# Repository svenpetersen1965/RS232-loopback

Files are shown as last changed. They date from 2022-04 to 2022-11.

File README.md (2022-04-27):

# RS232-loopback
This is a loopback module for the serial interface (RS232 and TTL).

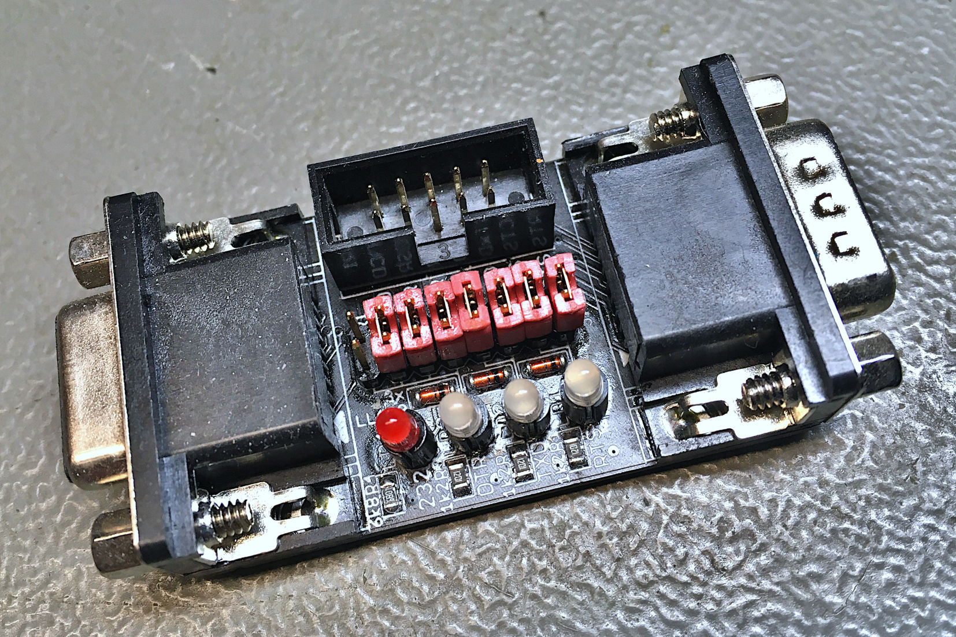
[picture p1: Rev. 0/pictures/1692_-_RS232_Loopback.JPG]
RS-232 loopback


It is useful for testing a serial interface. The sent data is echoed back, the RTS is fed back to CTS and DTR is looped back to DSR, DCD and RI. The feedbacks can be jumpered, the status is indicated on LEDs and it connects to DTE and DCE (9 pin D-Sub connectors). Also, there is a box connector for connecting a ribbon cable.

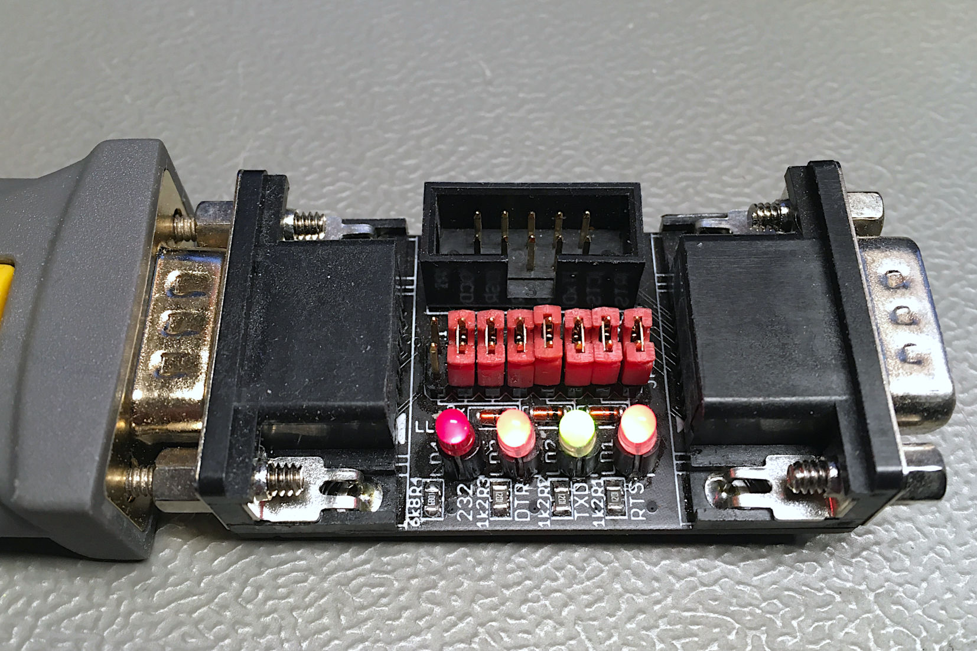
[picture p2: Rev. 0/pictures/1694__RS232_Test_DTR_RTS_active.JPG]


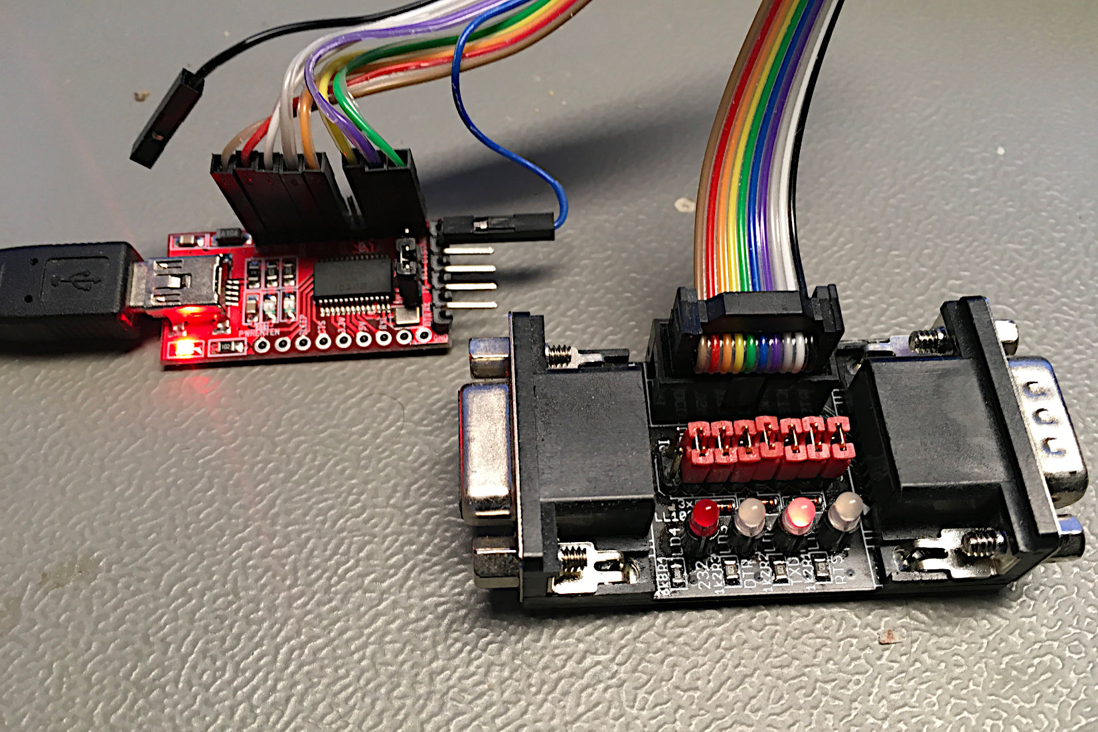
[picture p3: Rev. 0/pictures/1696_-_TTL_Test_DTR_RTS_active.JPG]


Please refer to the documentation in the pdf subdirectory.

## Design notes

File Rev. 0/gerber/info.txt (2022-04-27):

      
       Board: RS-232 Loopback
       Rev.:  0
  
       Files:
       ======
  
       All Gerber files are generated in extended gerber format (RS274X)
       *.TOP        : Film top copper
       *.BOT        :  -"- bottom copper
       *.STC        :  -"- top soldermask 
       *.STS        :  -"- bottom soldermask
       *.PLC        :  -"- silk screen top
       *.PLS        :  -"- silk screen bottom
       *.CRC        :  -"- cream top
       *.DK         : Drills plated Through (Excellon)
       *.NDK        : Drills not plated Through (Excellon)
       *.OUT        : Board outline

       Board Size:
       ===========
       Length     :   54.5 mm
       Width      :   30.5 mm
       Thickness  :   1.6 mm
       Material   :   FR 4
       Copper     :   35 um
       Surface    :   HASL
       
       Remarks: 
       ========

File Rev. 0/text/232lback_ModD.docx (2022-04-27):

RS-232 Loopback Rev.0

Module description

# Introduction

The RS-232 loopback is a tool for testing or sniffing an RS-232/TTL serial interface. It has a female (DTE/computer side) D-Sub (9 pins) connector, a male (DCE/modem side) D-Sub (9 pin) and a 2x5 box connector/pin header, which is configured for connecting the RS232 via a ribbon cable.

There are three feedbacks, that can be jumpered. The status of each feedback is indicated with a bi-color LED.

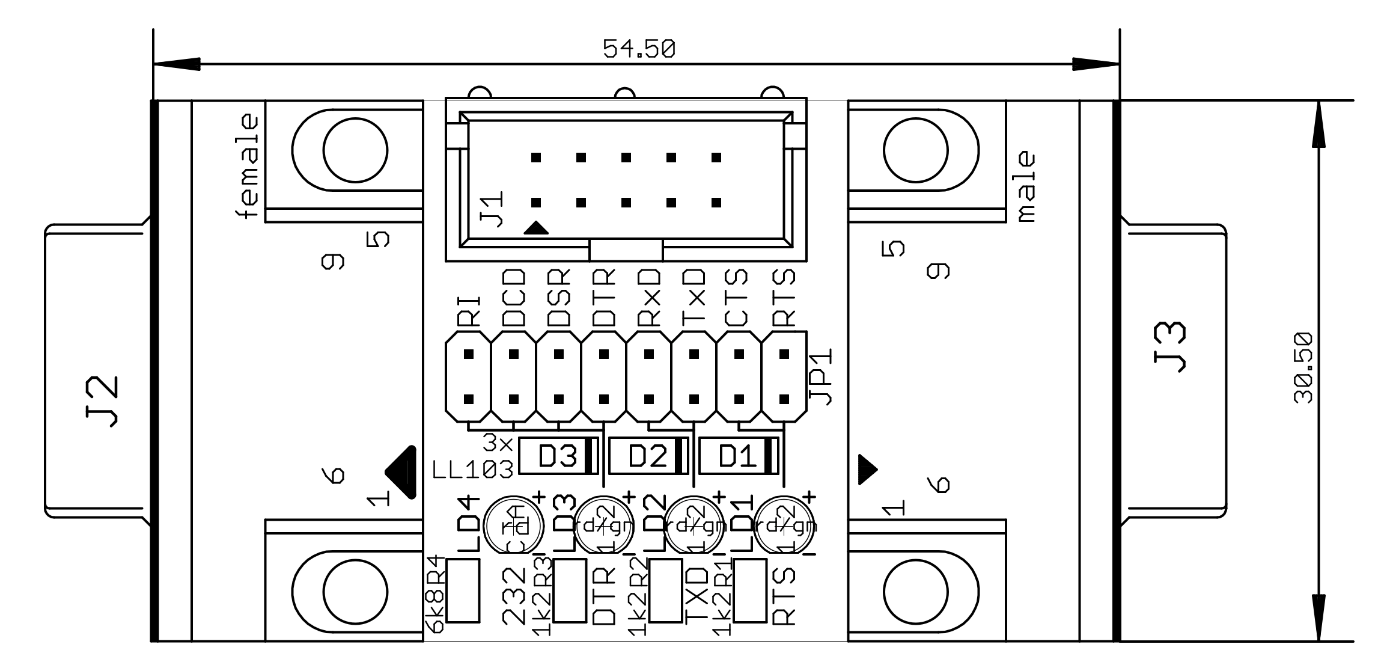
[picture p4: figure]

Figure 1: Dimensions of the RS-232 Loopback

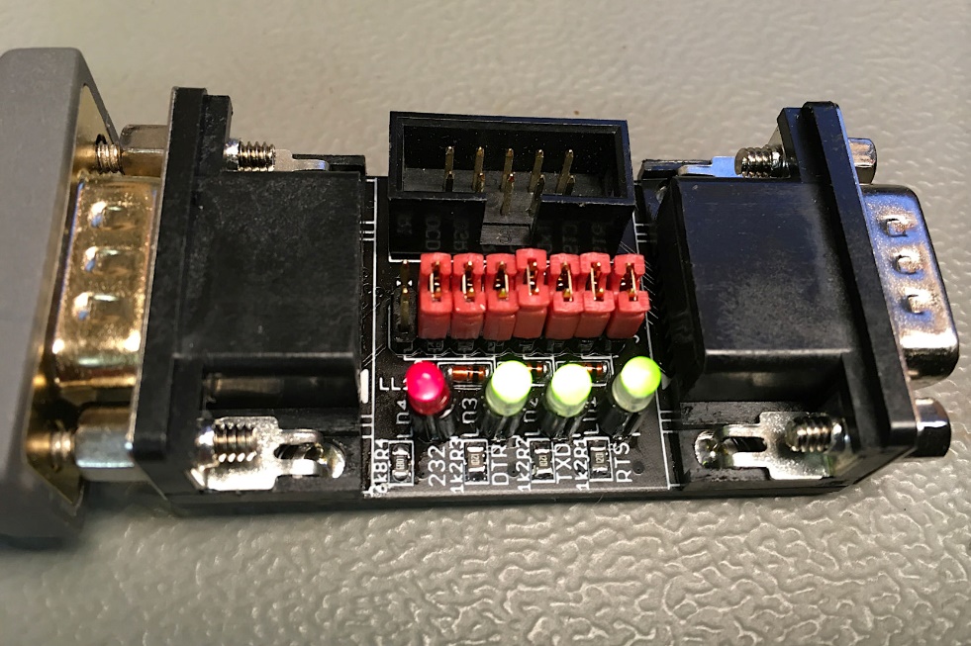
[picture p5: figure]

Figure 2: Connected RS-232 loopback

# Feedbacks /Jumper/Indicators

## Jumper J1

Feedback | Signals | Jumper JP1 | LED
RTS | RTS CTS | 1-2 3-4 | LD1
TXD | TxD RxD | 5-6 7-8 | LD2
DTR | DTR DSR DCD RI | 9-10 11-12 13-14 15-16 | LD3

## LEDs

### RS-232

RxD, TxD: The voltage level for a logic “0” (aka “space”) is +3V to +15V, for logic “1” (aka “mark”) it is -3V to -15V. voltages between -3V to +3V are an “illegal state”. For the handshake signals (RTS, CTS, DTR, DSR, DCD and RI) active is a positive +3V to +15V, while not active is negative -3V to -15V).

The RTS and DTR LEDs are red while active and green while not active. When idle, the TxD LED LD2 is green (indicating a negative voltage level) and blinking while data is being transferred.

### TTL

The RTS and DTR LEDs are off while active (LOW) and red while not active (HIGH). These signals are active low in TTL level). While idle, the TxD LED (LD2) is on.

### Level Indicator

There is a 4th LED (LD4) indicating the level: RS-232 (on), TTL (off).

# Connectors

## J1 (Box connector to DTE/Computer)

This is a 2x5 pin box connector. It is configured to fit a ribbon cable to a 2.54mm pitch pin header on a motherboard of a computer or to connect a D-Sub connector

Signal | Pin | Pin | Signal
DCD | 1 | 2 | DSR
RxD | 3 | 4 | RTS
TxD | 5 | 6 | CTS
DTR | 7 | 8 | RI
GND | 9 | 10 | -

## J2 (to DTE/Computer)

This is a female 9 pin D-Sub connector. It has the standard pinout of a modem side and fits directly or via a modem cable into the serial port of a computer.

Signal | Pin | Pin | Signal
DCD | 1 | 6 | DSR
RxD | 2 | 7 | RTS
TxD | 3 | 8 | CTS
DTR | 4 | 9 | RI
GND | 5

## J3 (to DCE/modem)

This is a male 9 pin D-Sub connector. It has the standard pinout of the serial interface of a computer/DTE and fits directly or via a modem cable into the serial port of a modem/DCE.

Signal | Pin | Pin | Signal
DSR | 6 | 1 | DCD
RTS | 7 | 2 | RxD
CTS | 8 | 3 | TxD
RI | 9 | 4 | DTR
| | 5 | GND

# Revision History

## Rev. 0

- Prototype: fully functional

232lback_ModD.docx 27.04.2022 16:35 Drafted by Sven Petersen Page 2 of 2 Doc.-No.: 183-6-01-00

232lback_ModD.docx 27.04.2022 16:35 Drafted by Sven Petersen Page 1 of 1 Doc.-No.: 000-6-00-00

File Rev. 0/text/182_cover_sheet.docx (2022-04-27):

Project Documentation

RS-232 Loopback

Project number: 183

Revision: 0

Date: 27.04.2022

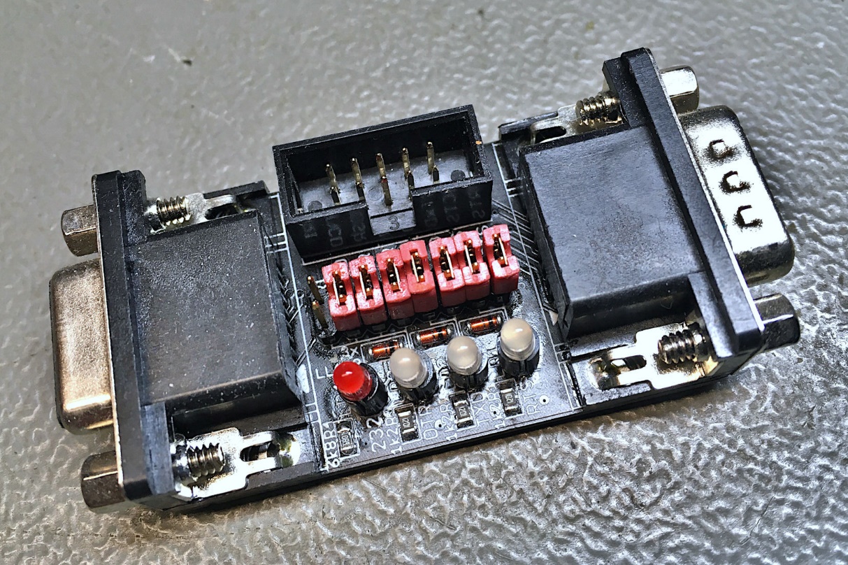
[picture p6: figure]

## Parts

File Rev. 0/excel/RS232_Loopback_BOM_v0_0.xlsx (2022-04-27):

RS-232 Loopback Rev. 0
Bill of Material Rev. 0.0
Pos. | Qty | Value | Footprint | Ref.-No. | Comment
1 | 1 | 183-2-01-00 | 2 Layer | PCB Rev. 0 | 2 layer, Cu 35µ, HASL, 54.5mm x 30.5mm, 1.6mm FR4
2 | 1 | box header, 2x5, 2.54mm | 2X05WV | J1 | e.g. Reichelt WSL 10G
3 | 1 | LED, 3mm green | 3MM | LD4 | standard LED
4 | 3 | 1k2 | 805 | R1, R2, R3 | SMD metal film resistor, 5% or better
5 | 1 | 6k8 | 805 | R4 | SMD metal film resistor, 5% or better
6 | 1 | COMBI-8X2P | COMBI-8X2 | JP1 | solder bridges or 2x8 pin header
7 | 8 | Jumper, 2.54mm | jumper | (JP1) | standard jumper (rated 1A or more). E.G. Reichelt: JUMPER 2,54 SW, tme.eu: 63429-202LF
8 | 1 | D09F90CL | D09F90CL | J2 | DSUB, 9p, female, 90°. E.g. Reichelt D-SUB BU 09EU
9 | 1 | D09M90CL | D09M90CL | J3 | DSUB, 9p, male, 90°. E.g. Reichelt D-SUB ST 09EU
10 | 3 | L-937EGW | LED_3MM_BICOLOR | LD1, LD2, LD3 | bi-color 3mm LED (green, red), e.g. Kingbright, e.g. Reichelt LED 3 RG
11 | 3 | LL103A | SOD-80 | D1, D2, D3 | SMD schottky diode, e.g. Vishay

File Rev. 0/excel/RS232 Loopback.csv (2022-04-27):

Qty | Value | Device | Package | Parts | Description
1 |  | 2X05WV | 2X05WV | J1
1 |  | 3MM | 3MM | LD4
3 | 1k2 | R-0805 | 0805 | R1, R2, R3
1 | 6k8 | R-0805 | 0805 | R4
1 | COMBI-8X2P | COMBI-8X2P | COMBI-8X2 | JP1
1 | D09F90CL | D09F90CL | D09F90CL | J2
1 | D09M90CL | D09M90CL | D09M90CL | J3
3 | L-937EGW | L-937EGW | LED_3MM_BICOLOR | LD1, LD2, LD3
3 | LL103A | D-SOD80 | SOD-80 | D1, D2, D3
1 | OPEN_SOURCE_HW | OPEN_SOURCE_HW | OPENHW | U$44

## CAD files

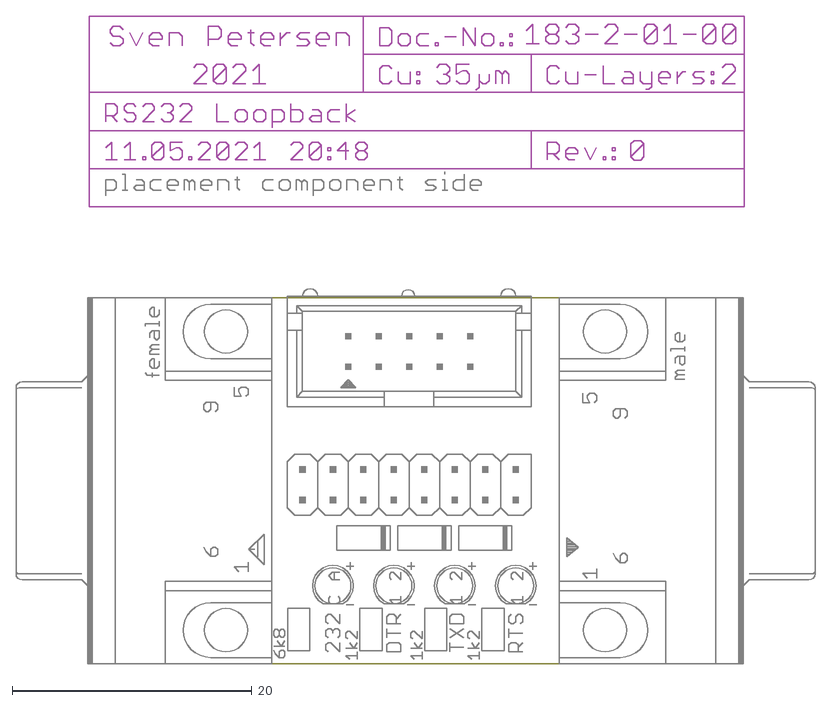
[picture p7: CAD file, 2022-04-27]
Rev. 0/dxf/RS232 Loopback.dxf
66.6 x 54.0

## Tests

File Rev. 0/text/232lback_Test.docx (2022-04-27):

RS-232 Loopback Rev.0

Testing

# Test Setup

1. RS-232 Loopback Rev. 0 (DUT, device under test)
2. USB to RS-232 converter/cable
3. USB to Serial (TTL/3.3V) converter board with FTDI FT232
4. Ribbon cable (Box connector to Dupont)
5. Terminal Software YAT (https://sourceforge.net/projects/y-a-terminal/)

The DUT was either connected via the serial cable or the FTDI board to the computer. The proper COM-port was selected in YAT.

# Test Execution

## Test via the USB to RS-232

For the test, all jumpers except the RI jumper were placed. The selected (YAT) baud rate was 9600.

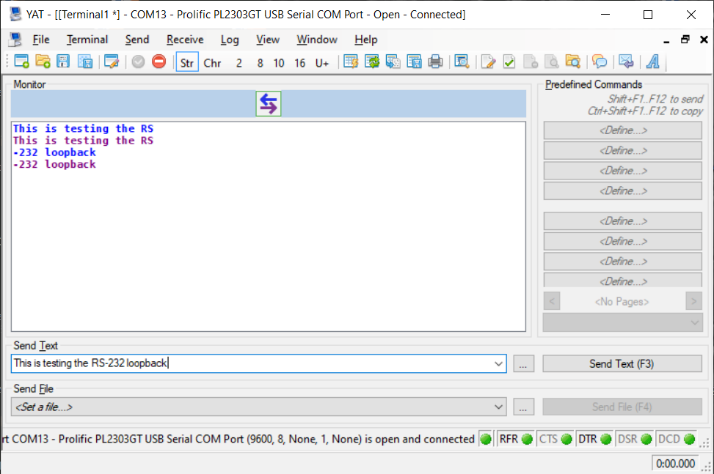
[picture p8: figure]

Figure 1: YAT - First test RTS (RFR) and DTS active

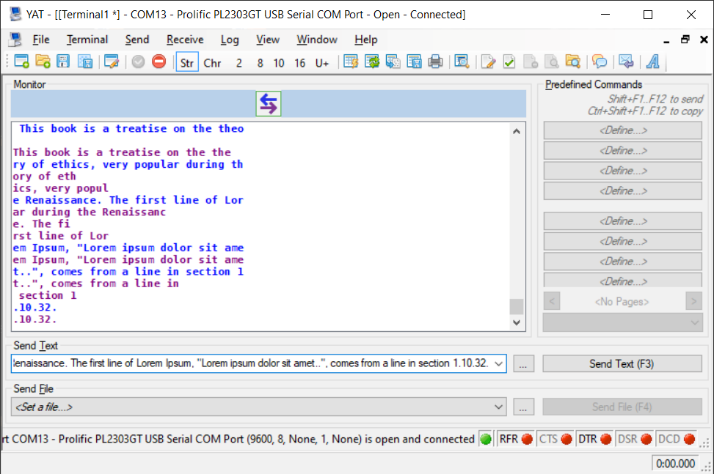
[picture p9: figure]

Figure 2: YAT - further testing RTS (RFR) and DTR inactive

While the data (text) is being transferred, the TxD LED LD2 is flickering. The sent text is being echoed by the loopback (as desired). The received (looped back) text is identical with the sent text. The line break is not, which is matter of the software.

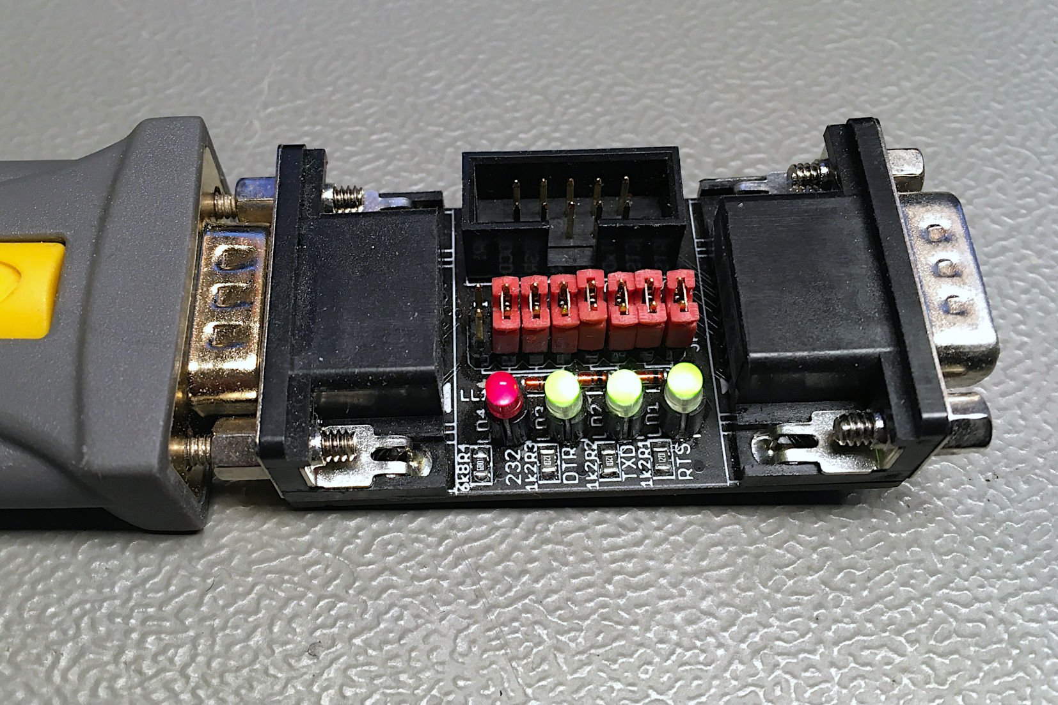
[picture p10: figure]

Figure 3: The RS-232 loopback connected to the RS-232 cable, RTS and DTR is inactive

The Level-Indicator LED lights (dim), while inactive and idling, all three bi-color LEDs (LD1-3) are green.


Figure 4: connected to RS-232, RTS and DTR active

When the status of RFR (RTS) is changed, the looped back status on CTS (indicated by YAT) changes accordingly. The same happens with DSR and DCD, if the DTR status is changed.

## Test via the USB to serial board (TTL)

The USB to serial board is connected to the box connector with the ribbon cable.


Figure 5: Test with the USB - (TTL) serial converter. Status: idle, RTS and DTR active

The level indicator LED LD4 (left, Figure 5) is off.

While data is being transferred, the TXD LED (LD2) is flickering. The RTS LED (LD1) is off while active and on while RTS is inactive. The DTR LED (LD3) indicated the DTR status correctly, too. The transmitted data is echoed back and the (this way) received text is identical with the transmitted text.

# Conclusion

The prototype is fully functional.

232lback_Test.docx 27.04.2022 16:35 Drafted by Sven Petersen Page 2 of 2 Doc.-No.: 183-6-02-00

232lback_Test.docx 27.04.2022 16:35 Drafted by Sven Petersen Page 1 of 1 Doc.-No.: 000-6-00-00

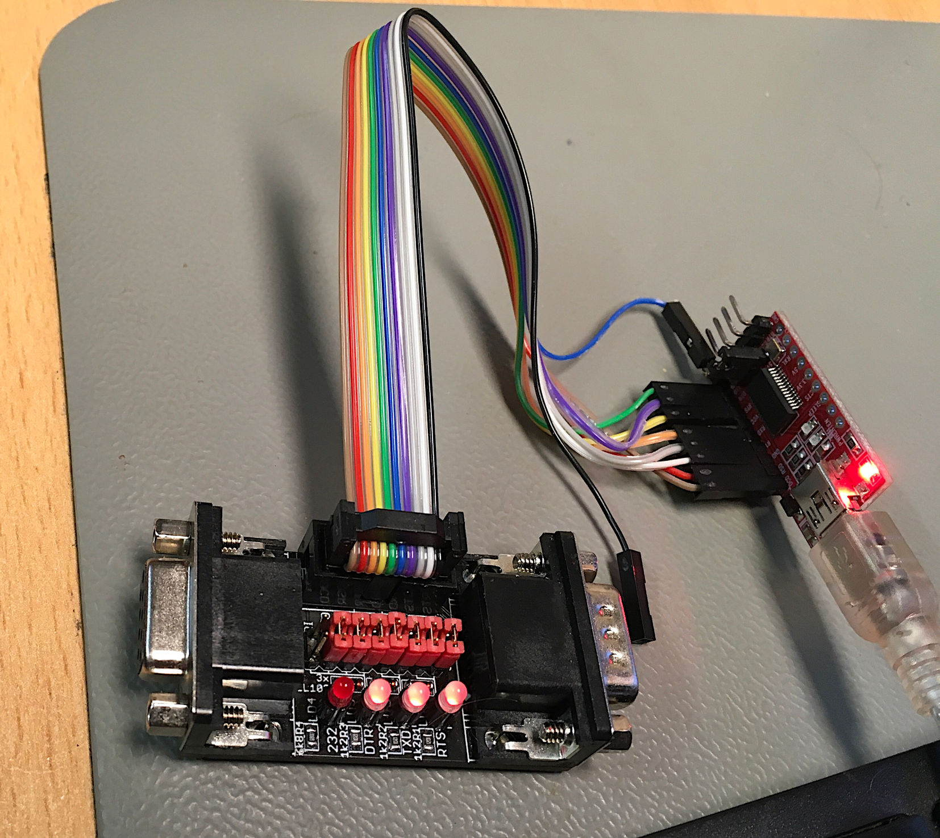
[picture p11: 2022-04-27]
Rev. 0/pictures/9595_-__TTL_Test_DTR_RTS_inactive.JPG

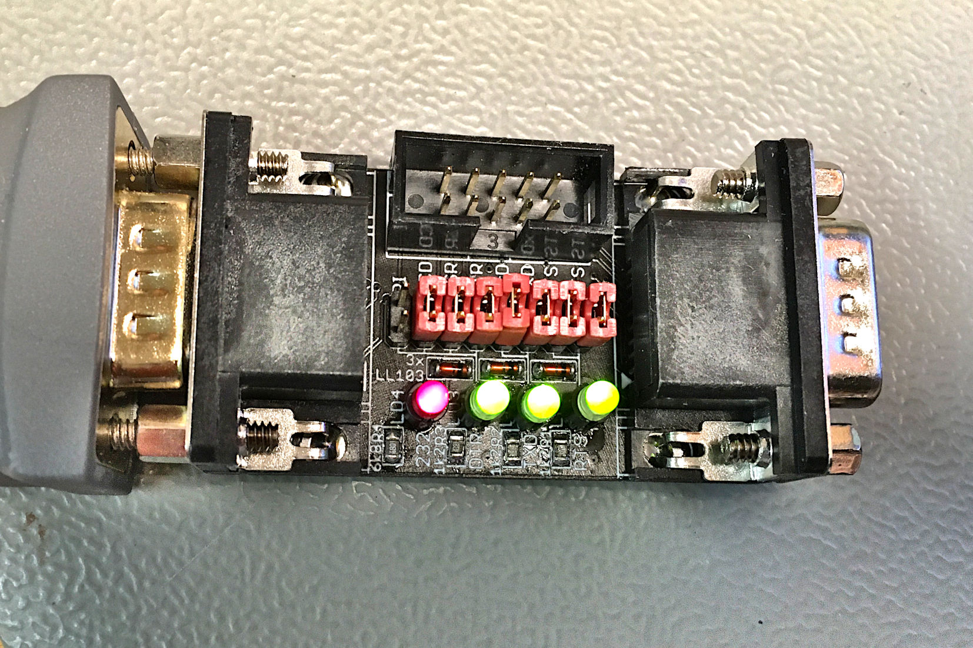
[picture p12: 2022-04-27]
Rev. 0/pictures/9485_-_Test_RS232_DTR_RTS_inactive.JPG

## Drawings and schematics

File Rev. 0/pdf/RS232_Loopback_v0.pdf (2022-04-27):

# Project Documentation

## RS-232 Loopback

## Project number: 183

## Revision: 0

## Date: 27.04.2022

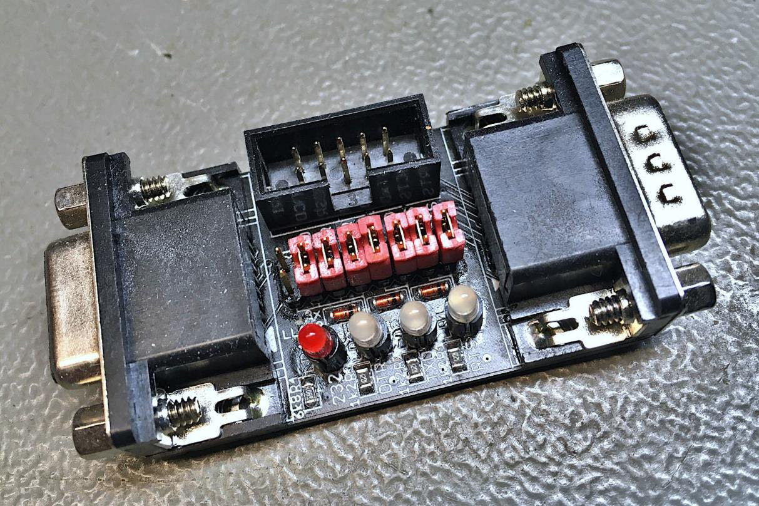
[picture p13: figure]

### RS-232 Loopback Rev.0

### Module description

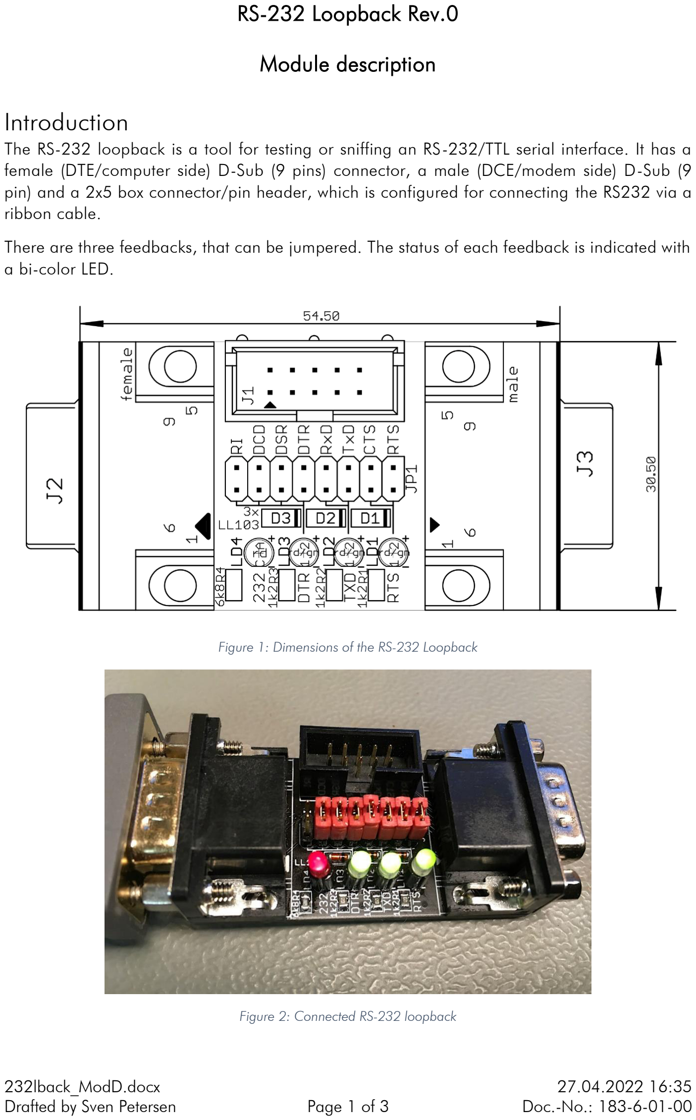
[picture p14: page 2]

232lback_ModD.docx | | 27.04.2022 16:35
Drafted by Sven Petersen | Page 1 of 3 | Doc.-No.: 183-6-01-00

## Introduction

The RS-232 loopback is a tool for testing or sniffing an RS-232/TTL serial interface. It has a female (DTE/computer side) D-Sub (9 pins) connector, a male (DCE/modem side) D-Sub (9 pin) and a 2x5 box connector/pin header, which is configured for connecting the RS232 via a ribbon cable.

There are three feedbacks, that can be jumpered. The status of each feedback is indicated with a bi-color LED.

Figure 1: Dimensions of the RS-232 Loopback

Figure 2: Connected RS-232 loopback

232lback_ModD.docx | | 27.04.2022 16:35
Drafted by Sven Petersen | Page 2 of 3 | Doc.-No.: 183-6-01-00

## Feedbacks /Jumper/Indicators

### Jumper J1

Feedback | Signals | Jumper JP1

LED

RTS | RTS CTS | 1-2 3-4 | LD1
TXD | TxD RxD | 5-6 7-8 | LD2
DTR | DTR DSR DCD RI | 9-10 11-12 13-14 15-16 | LD3

### LEDs

RS-232
RxD, TxD: The voltage level for a logic “0” (aka “space”) is +3V to +15V, for logic “1” (aka “mark”) it is -3V to -15V. voltages between -3V to +3V are an “illegal state”. For the handshake signals (RTS, CTS, DTR, DSR, DCD and RI) active is a positive +3V to +15V, while not active is negative -3V to -15V).

The RTS and DTR LEDs are red while active and green while not active. When idle, the TxD LED LD2 is green (indicating a negative voltage level) and blinking while data is being transferred.

TTL
The RTS and DTR LEDs are off while active (LOW) and red while not active (HIGH). These signals are active low in TTL level). While idle, the TxD LED (LD2) is on.

Level Indicator
There is a 4th LED (LD4) indicating the level: RS-232 (on), TTL (off).

## Connectors

### J1 (Box connector to DTE/Computer)

This is a 2x5 pin box connector. It is configured to fit a ribbon cable to a 2.54mm pitch pin header on a motherboard of a computer or to connect a D-Sub connector

Signal Pin | Pin Signal
DCD | 1 | 2 | DSR
RxD | 3 | 4 | RTS
TxD | 5 | 6 | CTS
DTR | 7 | 8 | RI
GND | 9 | 10 | -

### J2 (to DTE/Computer)

This is a female 9 pin D-Sub connector. It has the standard pinout of a modem side and fits directly or via a modem cable into the serial port of a computer.

Signal Pin | Pin Signal
DCD | 1 | 6 | DSR

232lback_ModD.docx | | 27.04.2022 16:35
Drafted by Sven Petersen | Page 3 of 3 | Doc.-No.: 183-6-01-00
RxD | 2 | 7 | RTS
TxD | 3 | 8 | CTS
DTR | 4 | 9 | RI
GND | 5

### J3 (to DCE/modem)

This is a male 9 pin D-Sub connector. It has the standard pinout of the serial interface of a computer/DTE and fits directly or via a modem cable into the serial port of a modem/DCE.

Signal Pin | Pin Signal
DSR | 6 | 1 | DCD
RTS | 7 | 2 | RxD
CTS | 8 | 3 | TxD
RI | 9 | 4 | DTR
| | 5 GND

## Revision History

### Rev. 0

- Prototype: fully functional

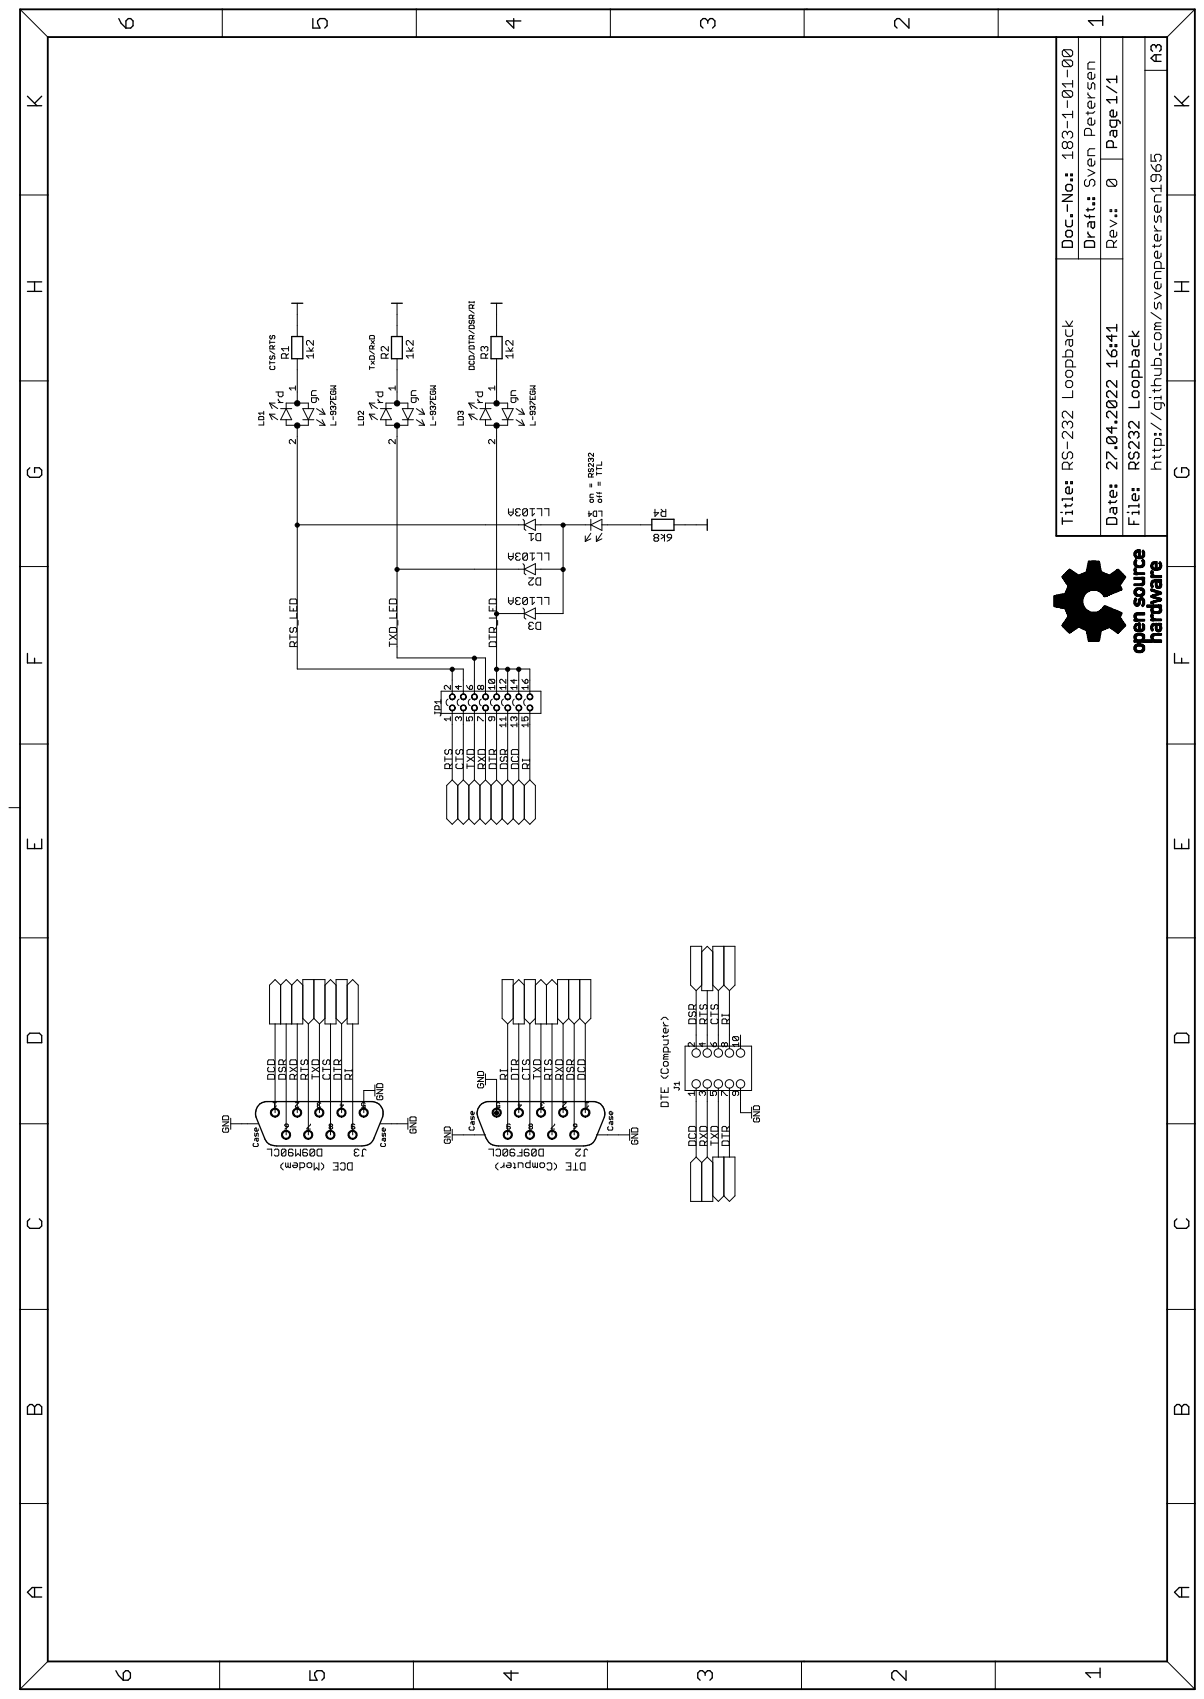
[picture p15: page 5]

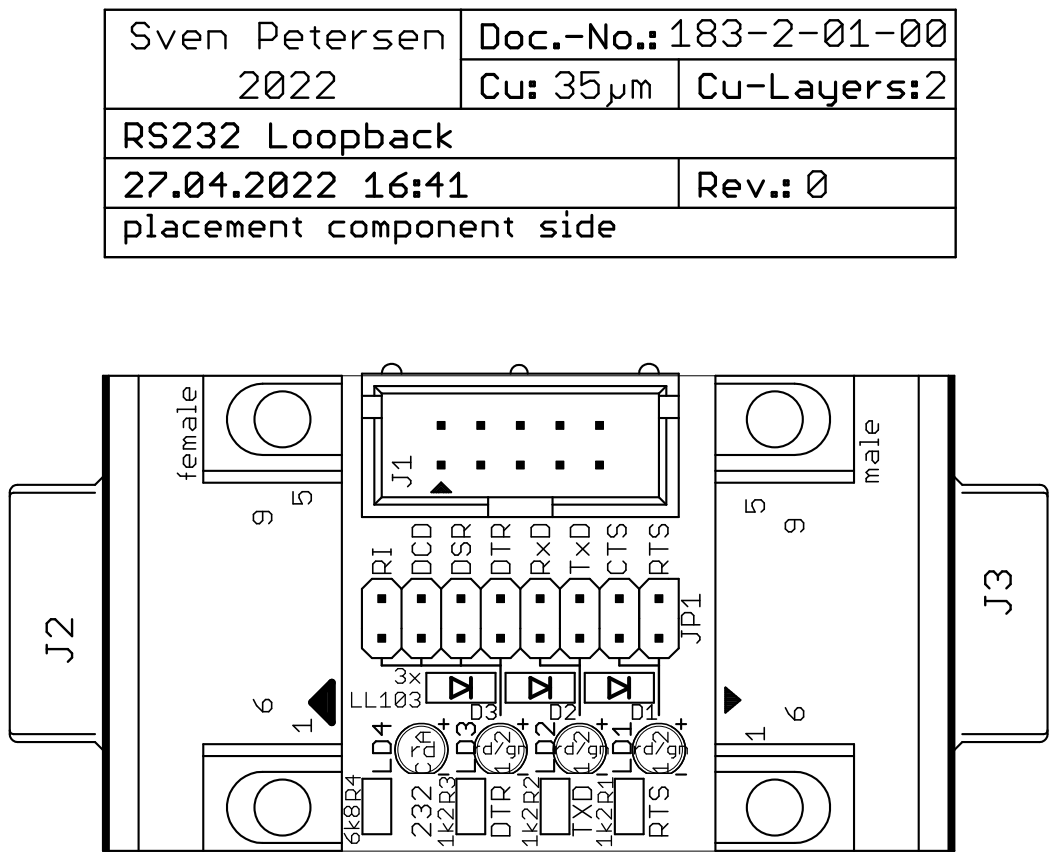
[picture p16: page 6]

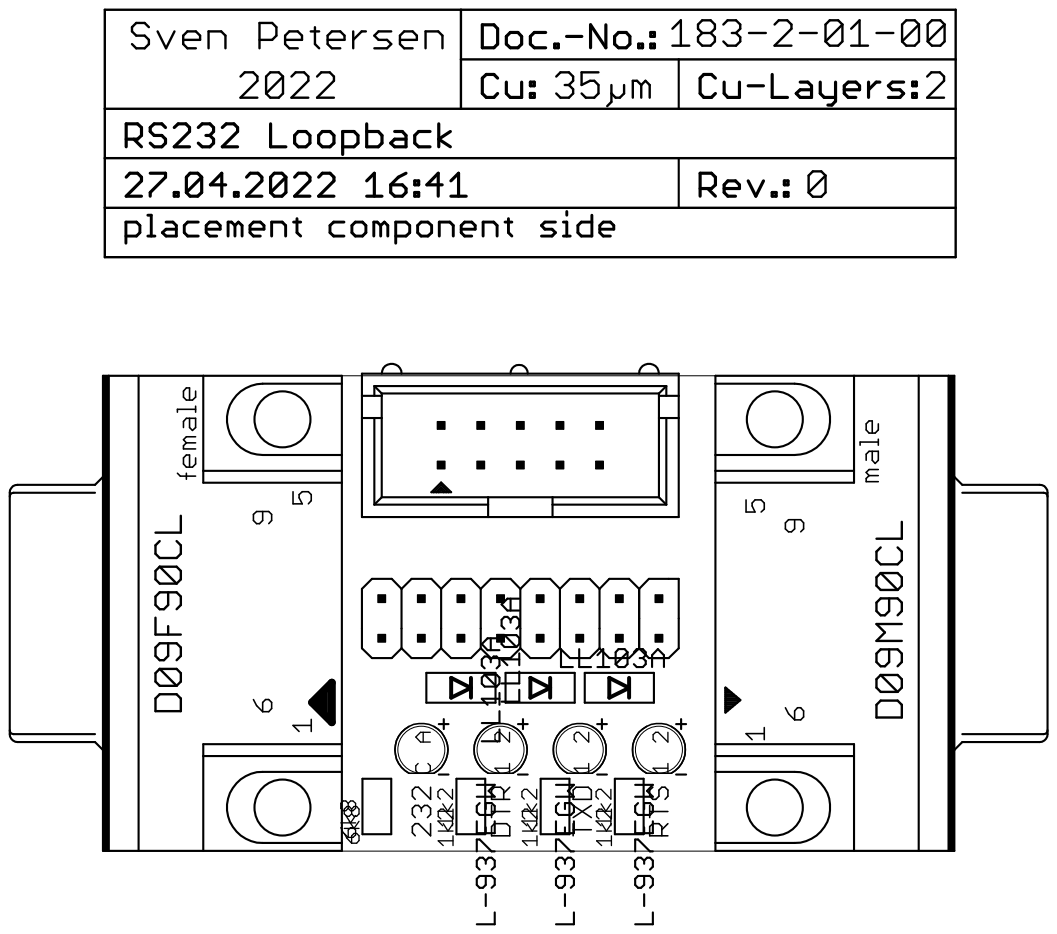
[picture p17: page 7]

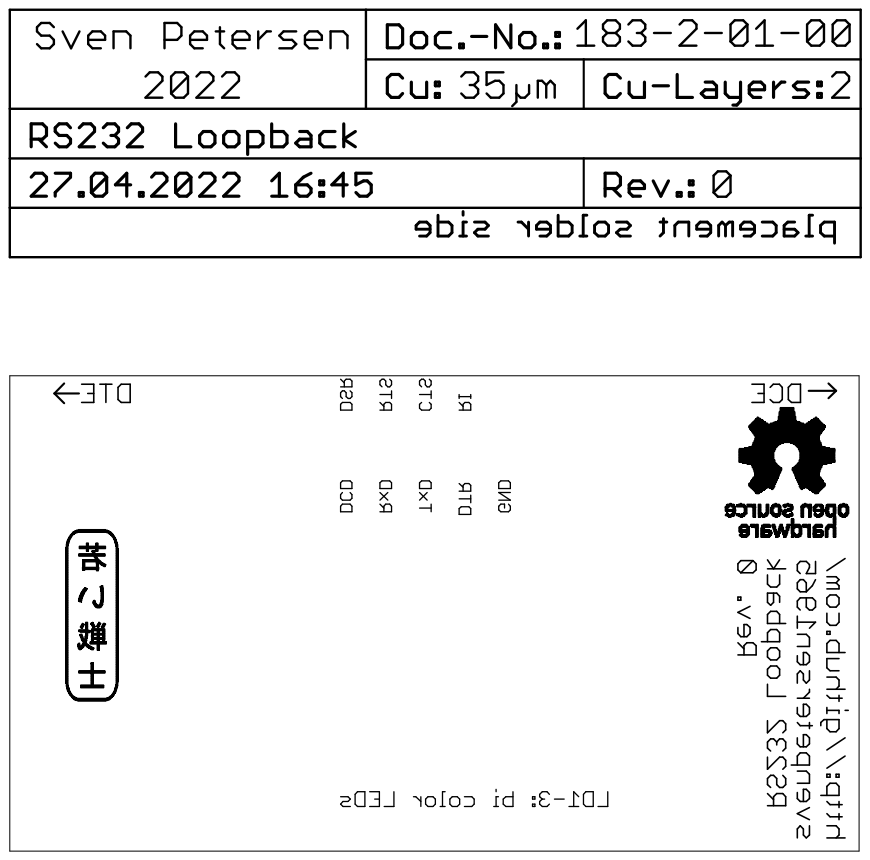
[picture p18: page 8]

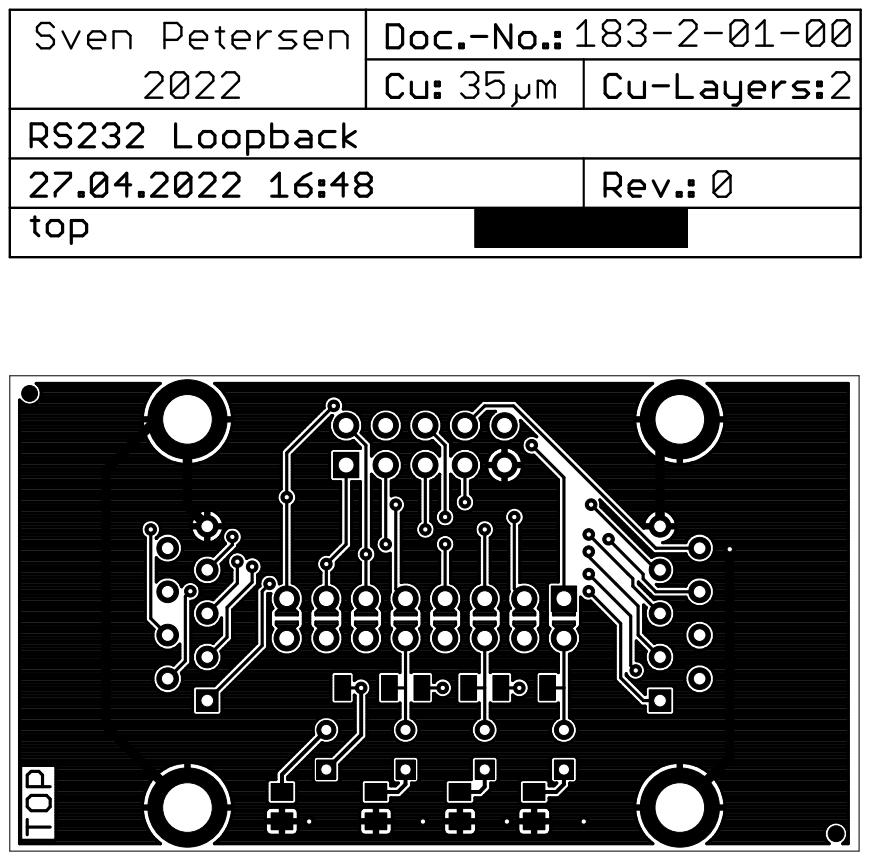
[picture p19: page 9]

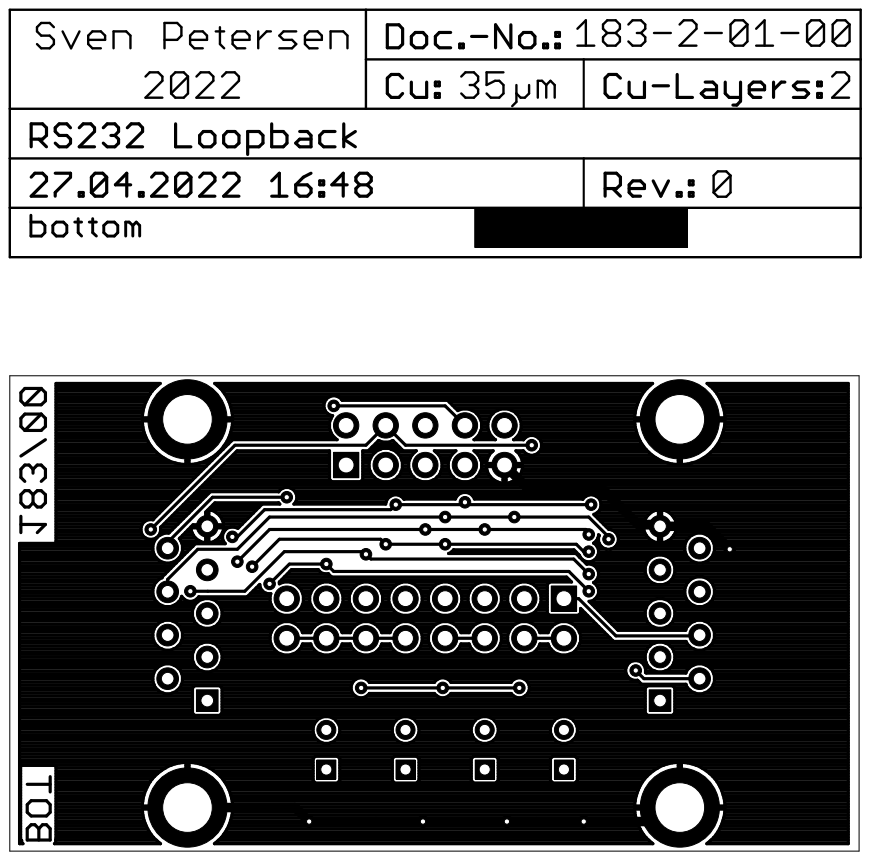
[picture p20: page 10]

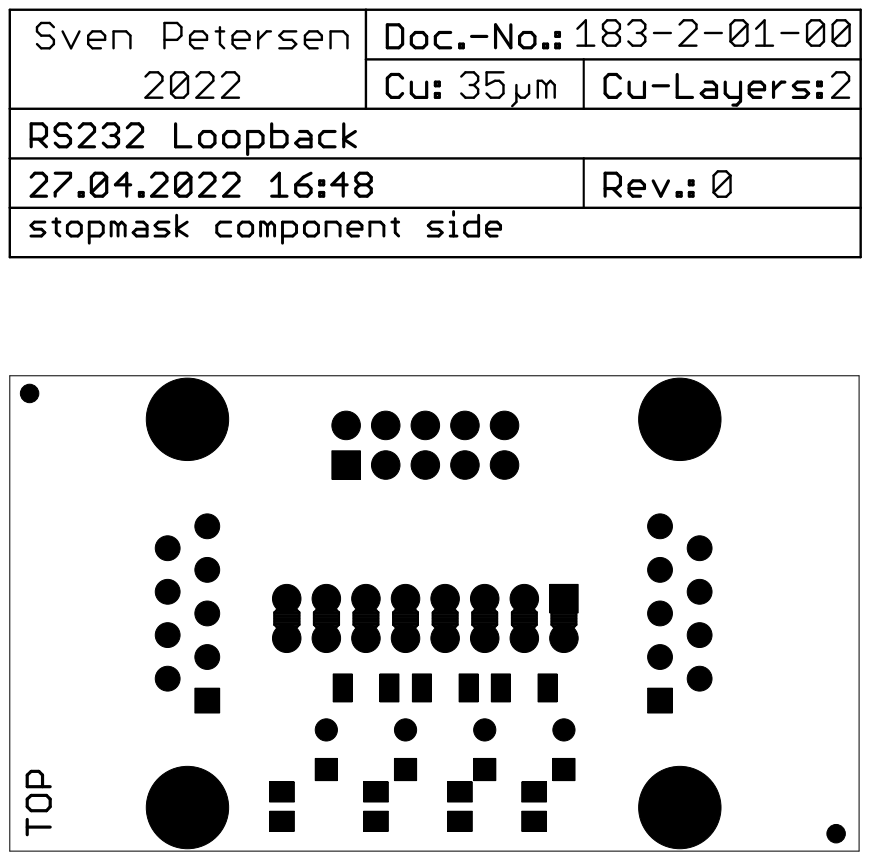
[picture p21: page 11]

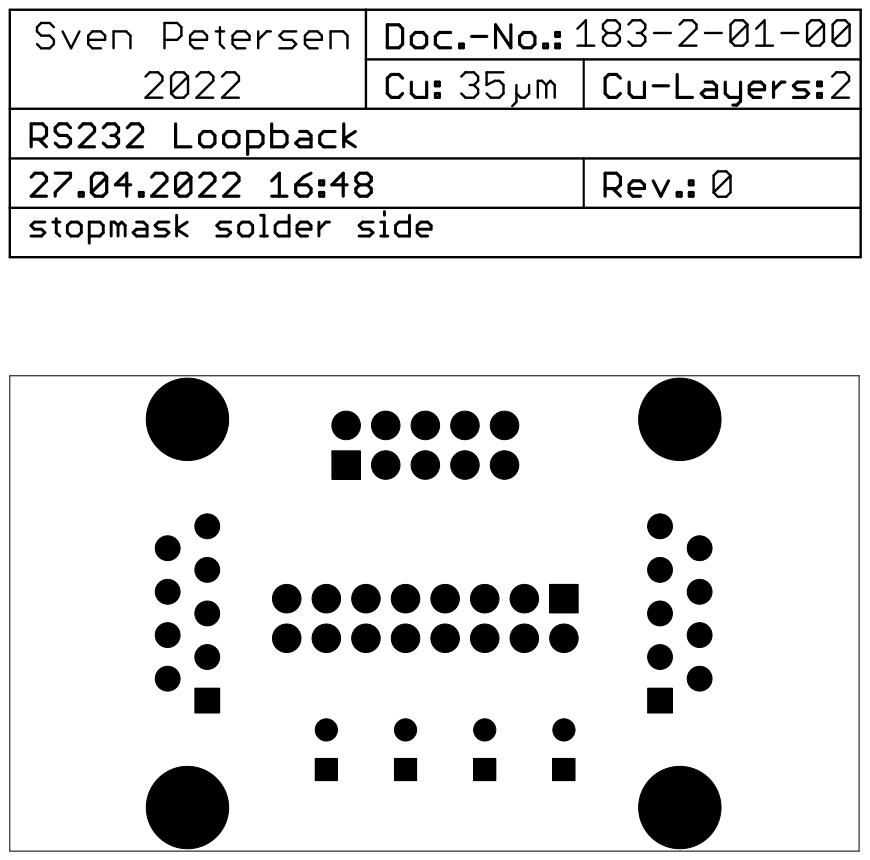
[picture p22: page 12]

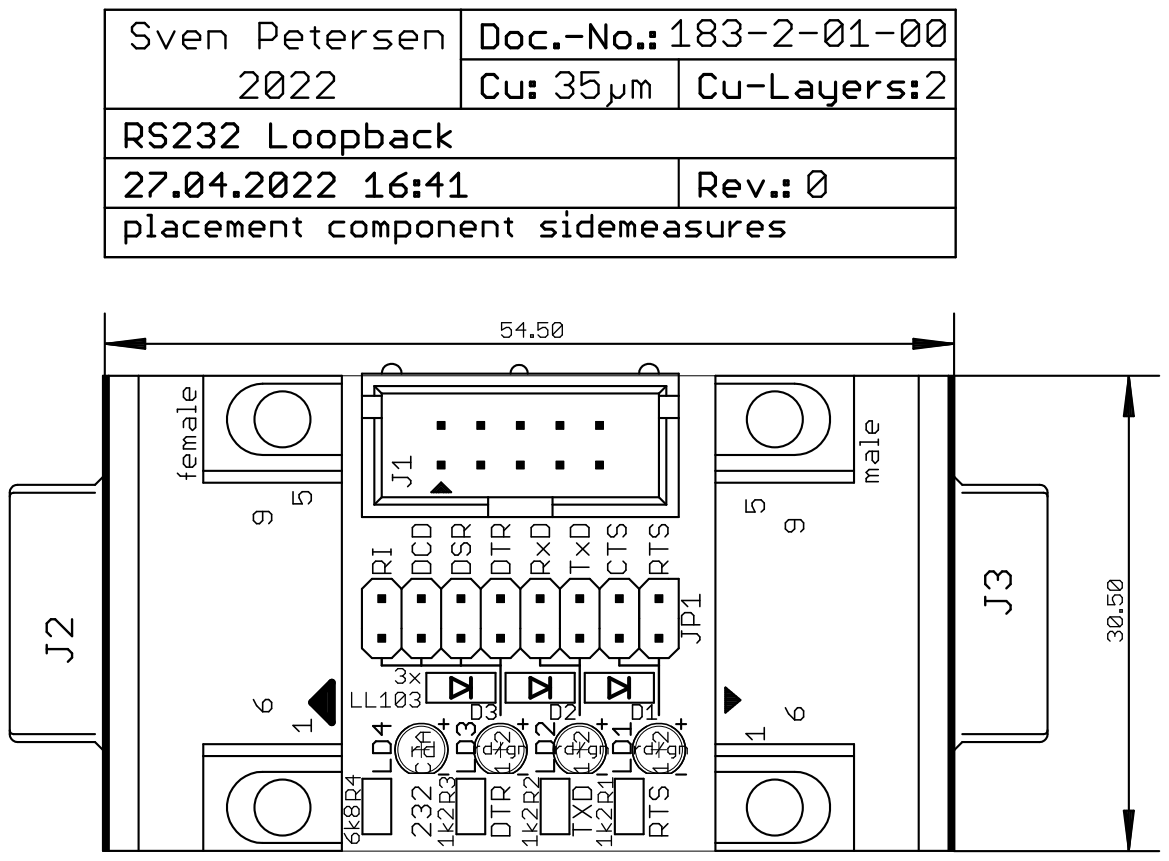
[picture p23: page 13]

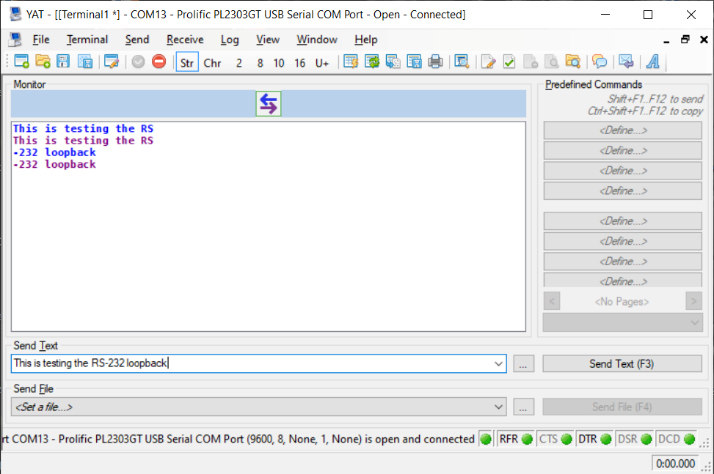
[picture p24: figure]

232lback_Test.docx | | 27.04.2022 16:35
Drafted by Sven Petersen | Page 1 of 3 | Doc.-No.: 183-6-02-00

### RS-232 Loopback Rev.0

### Testing

## Test Setup

### 1. RS-232 Loopback Rev. 0 (DUT, device under test) 2. USB to RS-232 converter/cable 3. USB to Serial (TTL/3.3V) converter board with FTDI FT232 4. Ribbon cable (Box connector to Dupont) 5. Terminal Software YAT (https://sourceforge.net/projects/y-a-terminal/)

The DUT was either connected via the serial cable or the FTDI board to the computer. The proper COM-port was selected in YAT.

## Test Execution
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

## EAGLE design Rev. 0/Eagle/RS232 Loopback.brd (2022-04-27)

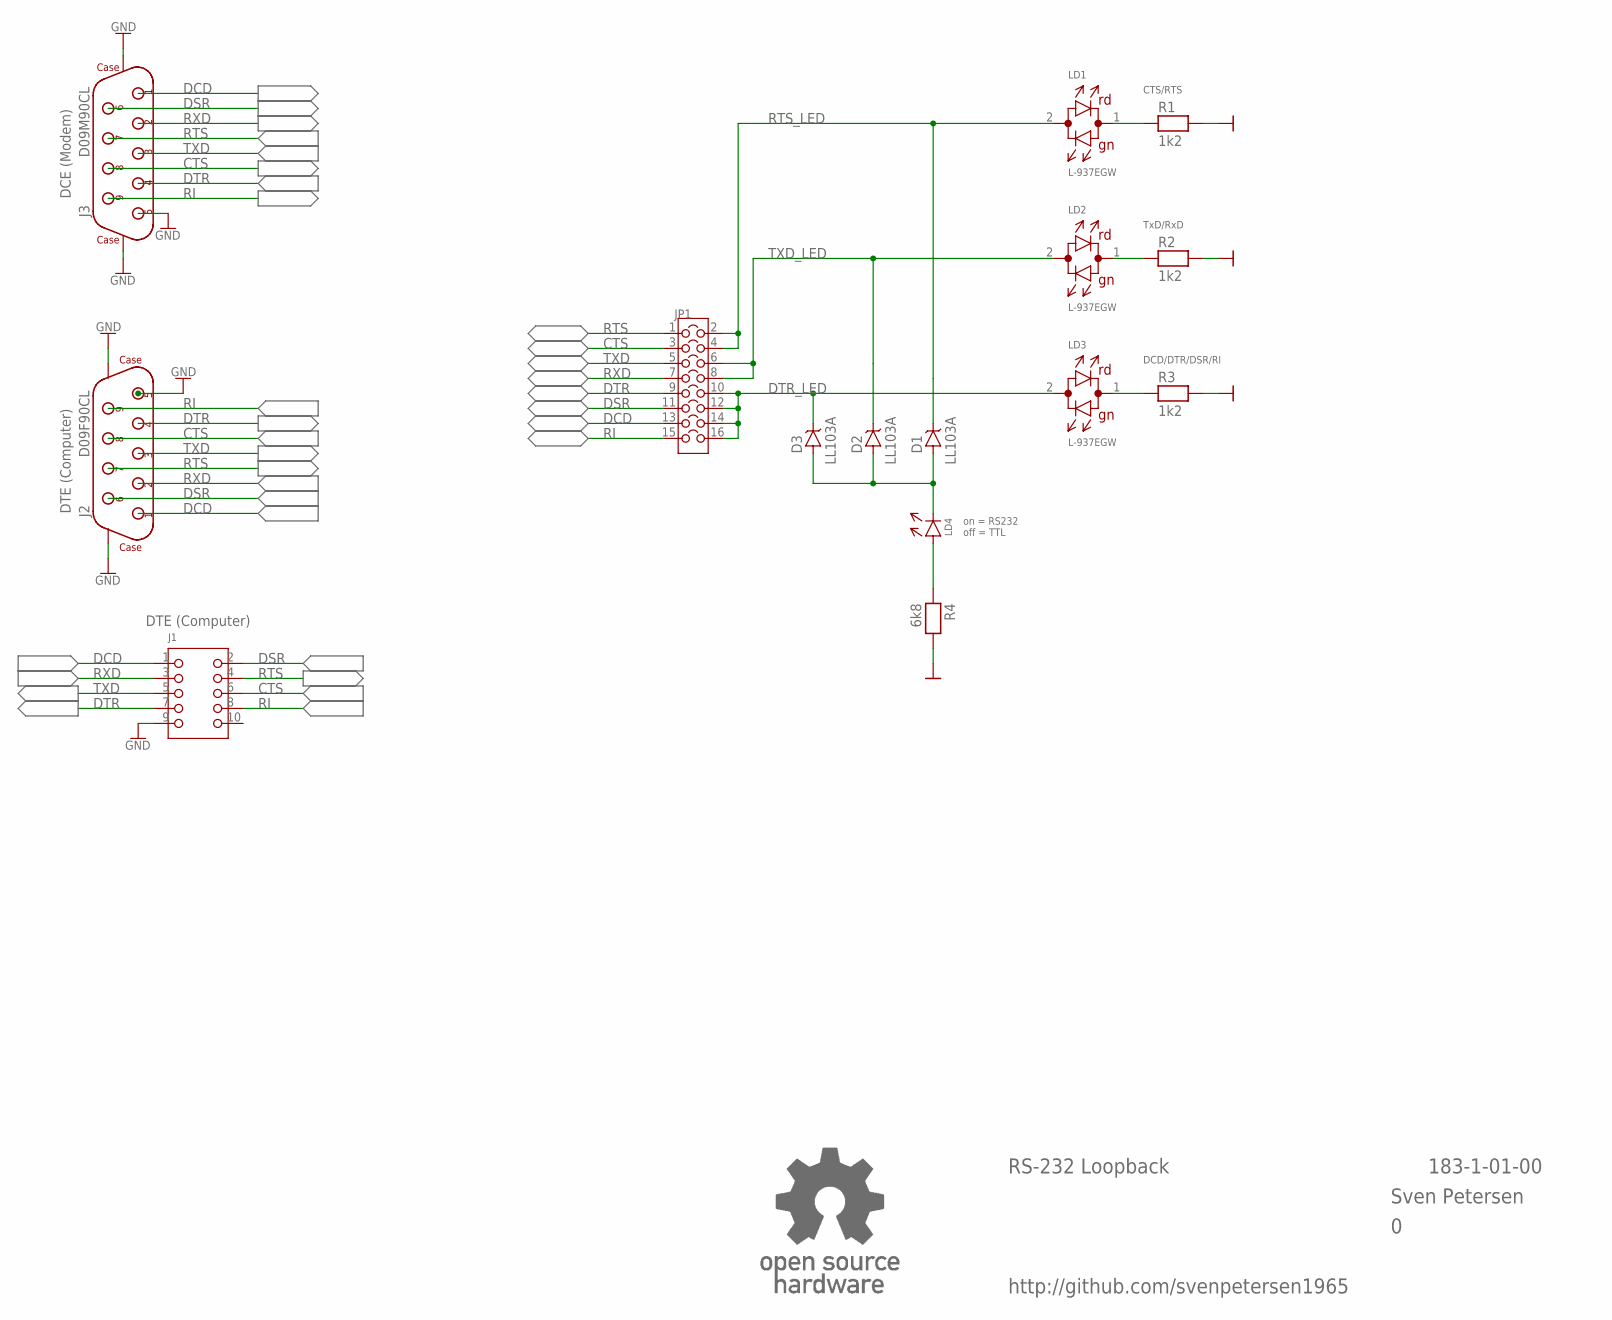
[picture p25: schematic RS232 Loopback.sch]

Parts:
D1, D2, D3: LL103A; SOD80C
J1: 2X05WV
J2: D09F90CL
J3: D09M90CL
JP1: COMBI-8X2P; COMBI-8X2
LD1, LD2, LD3: L-937EGW; LED_3MM_BICOLOR
LD4: 3MM
R1, R2, R3: 1k2; 0805
R4: 6k8; 0805
U$44: OPEN_SOURCE_HW; OPENHW

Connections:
CTS: J1.6, J2.8, J3.8, JP1.3
DCD: J1.1, J2.1, J3.1, JP1.13
DSR: J1.2, J2.6, J3.6, JP1.11
DTR: J1.7, J2.4, J3.4, JP1.9
DTR_LED: D3.K, JP1.10, JP1.12, JP1.14, JP1.16, LD3.2
GND: J1.9, J2.5, J2.CL1 (CASE1), J2.CL2 (CASE2), J3.5, J3.CL1 (CASE1), J3.CL2 (CASE2), R1.2, R2.2, R3.2, R4.2
unnamed: D1.A, D2.A, D3.A, LD4.C (K)
unnamed: LD4.A, R4.1
unnamed: LD1.1, R1.1
unnamed: LD2.1, R2.1
unnamed: LD3.1, R3.1
RI: J1.8, J2.9, J3.9, JP1.15
RTS: J1.4, J2.7, J3.7, JP1.1
RTS_LED: D1.K, JP1.2, JP1.4, LD1.2
RXD: J1.3, J2.2, J3.2, JP1.7
TXD: J1.5, J2.3, J3.3, JP1.5
TXD_LED: D2.K, JP1.6, JP1.8, LD2.2

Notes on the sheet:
CTS/RTS
TxD/RxD
on = RS232 off = TTL
DCD/DTR/DSR/RI
DTE (Computer)
DCE (Modem)
http://github.com/svenpetersen1965
Sven Petersen
RS-232 Loopback
183-1-01-00

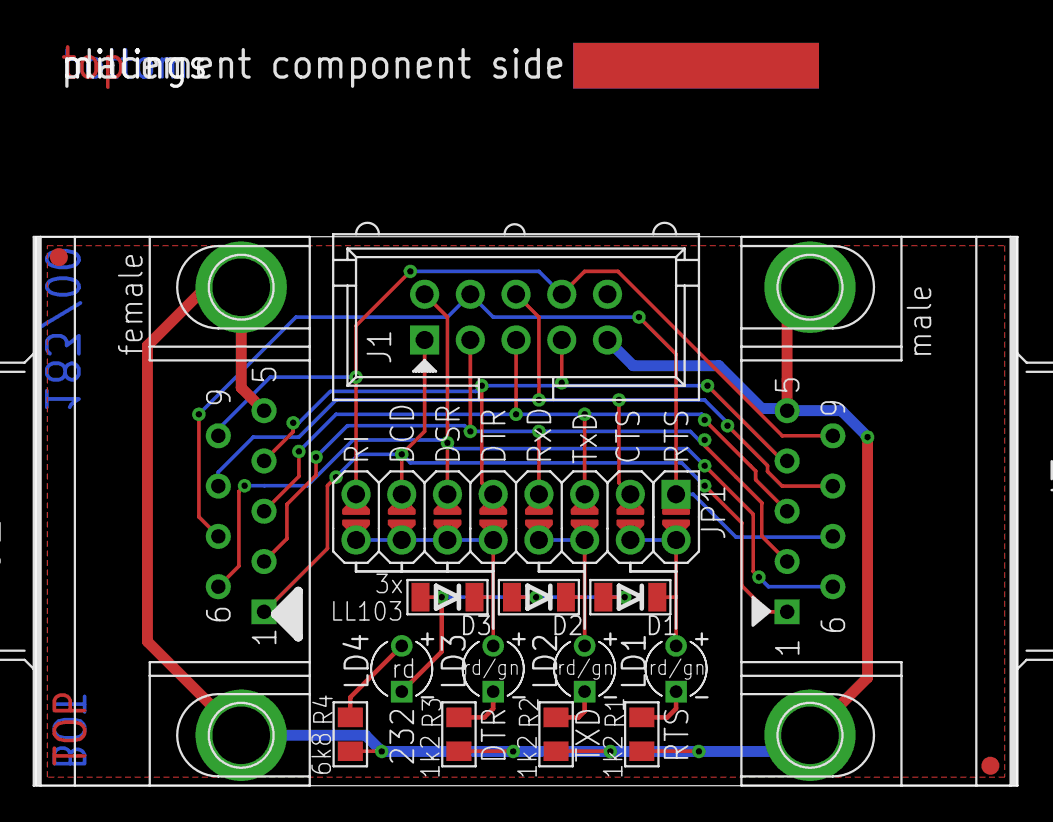
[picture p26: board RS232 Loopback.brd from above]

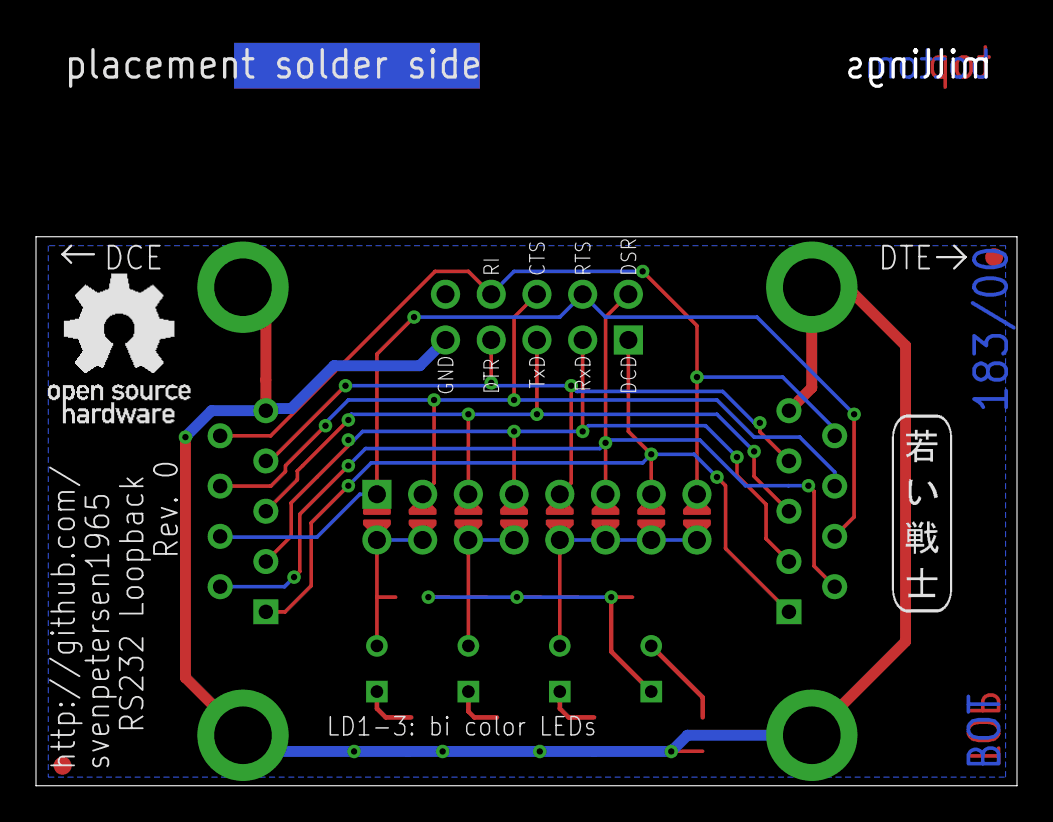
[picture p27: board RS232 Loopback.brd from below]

Board: 2 copper layers, 54.5 x 30.5 mm, 21 parts (2 on the bottom side), 17 nets.

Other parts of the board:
U$2: 2LAYER
U$3, U$43: SMD_REF_R1MM
U$45: PCB-TITLE/
U$46: SVEN_TAG
